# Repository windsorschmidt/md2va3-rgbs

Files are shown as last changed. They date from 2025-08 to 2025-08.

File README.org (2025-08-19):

* About

RGBS video and audio output board for Sega Genesis 2 VA3.

Based on the "Triple Bypass" (3BP for short) circuit originally from
René Richard.  Unlike the TBP which can be configured to work with
several types of Genesis consoles, this board is designed specifically
for the Genesis 2 VA3.

* Features

- Active buffer/amplifiers for audio and video
- Mounts inside console beside main PCB using existing mounting points
- RGBS output on DE-15 (VGA style) connector
- Audio output on 3.5mm phono jack

[[md2va3-rgbs.png?raw=true]]

* Status

Revision 2 PCB tested working.

* References

- https://github.com/db-electronics/triple-bypass-kicad
- https://github.com/tianfeng33/triple-bypass-Version-2

* License

Circuit schematic and PCB layout are licensed under CERN-OHL-S v2.

See [[LICENSE.txt]].

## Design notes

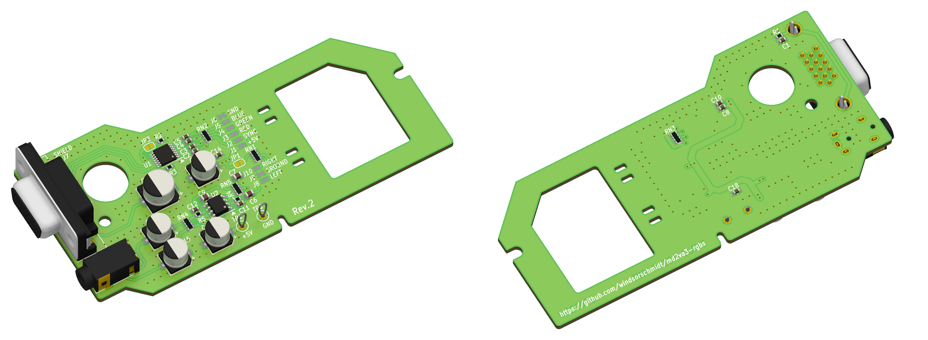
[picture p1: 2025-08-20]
md2va3-rgbs.png

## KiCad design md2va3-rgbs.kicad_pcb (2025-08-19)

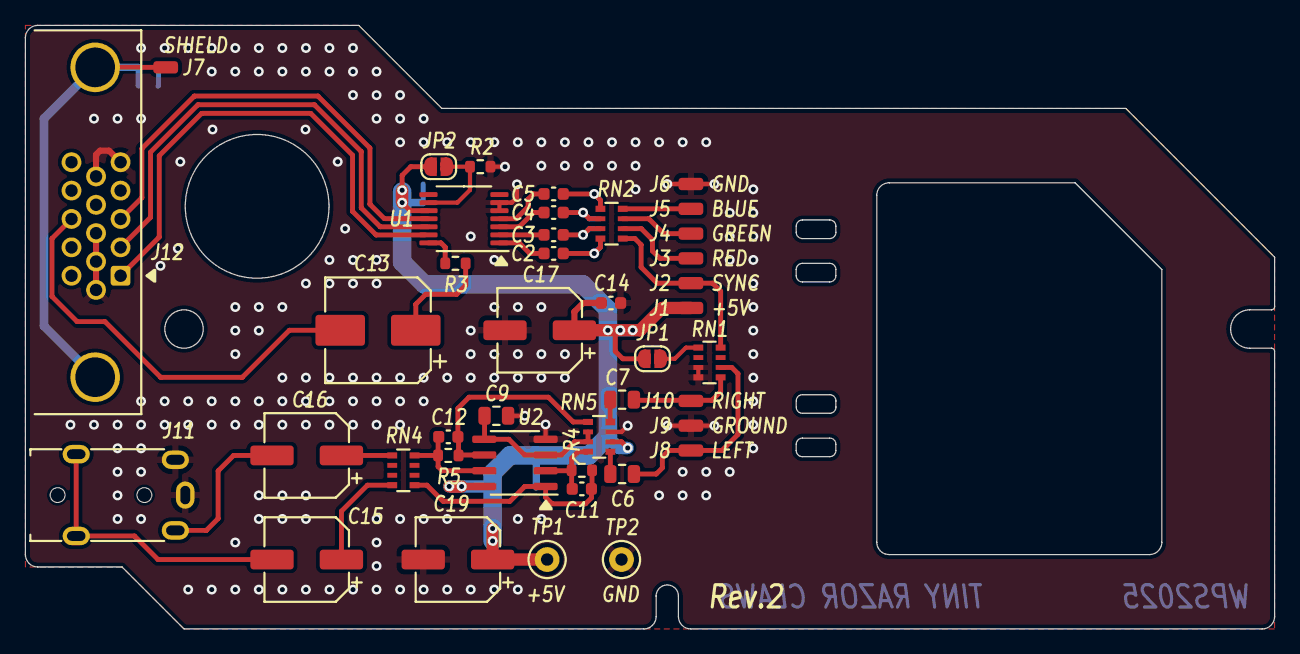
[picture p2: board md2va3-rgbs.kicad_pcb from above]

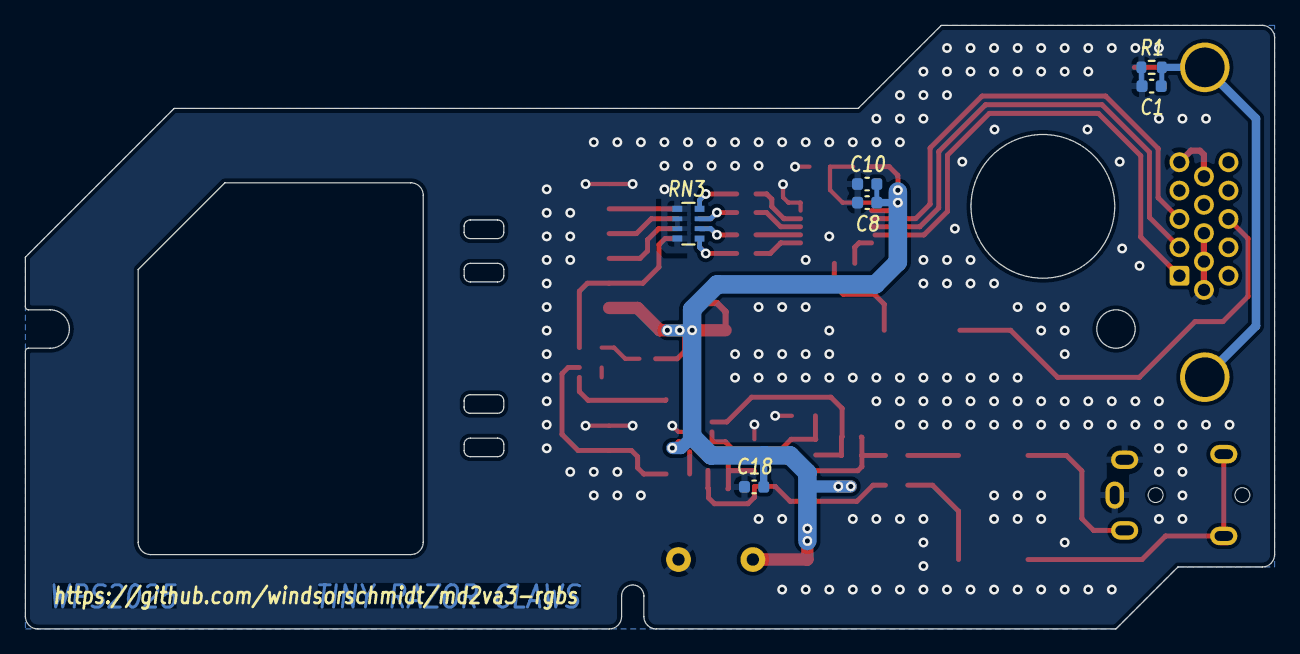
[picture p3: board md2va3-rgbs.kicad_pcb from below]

Board: 2 copper layers, 100.8 x 48.7 mm, 49 parts (6 on the bottom side), 36 nets.

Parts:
C1, C11, C12: 33p; C_0603_1608Metric
C2, C3, C4, C5, C14, C18: 100n; C_0603_1608Metric
C6, C7, C9: 10u; C_0805_2012Metric
C8: 10n; C_0603_1608Metric
C10: 1u; C_0603_1608Metric
C13: 220u; CP_Elec_8x6.2
C15, C16, C17, C19: 47u; CP_Elec_6.3x5.9
J1: +5V; SolderWirePad_1x01_SMD_1x2mm
J2: SYNC_TTL; SolderWirePad_1x01_SMD_1x2mm
J3: R; SolderWirePad_1x01_SMD_1x2mm
J4: G; SolderWirePad_1x01_SMD_1x2mm
J5: B; SolderWirePad_1x01_SMD_1x2mm
J6, J9: GND; SolderWirePad_1x01_SMD_1x2mm
J7: SHIELD; SolderWirePad_1x01_SMD_1x2mm
J8: LEFT; SolderWirePad_1x01_SMD_1x2mm
J10: RIGHT; SolderWirePad_1x01_SMD_1x2mm
J11: 54-00174; Jack_3.5mm_Tensility_54-00174
J12: HD15-SN-25; DSUB-15-HD_Female_Horizontal_P2.29x1.98mm_EdgePinOffset3.03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
JP1: SYNC_PU; SolderJumper-2_P1.3mm_Open_RoundedPad1.0x1.5mm
JP2: LPF; SolderJumper-2_P1.3mm_Open_RoundedPad1.0x1.5mm
MNT1, MNT2: MOUNT_ZIP_TIE; MountingHole_Zip_Tie
R1: 1M; R_0603_1608Metric
R2: 4.7k; R_0603_1608Metric
R3: 75; R_0603_1608Metric
R4, R5: 300k; R_0603_1608Metric
RN1: 2.2k; R_Array_Convex_4x0603
RN2: 5.62k; R_Array_Convex_4x0603
RN3: 1k; R_Array_Convex_4x0603
RN4: 330; R_Array_Convex_4x0603
RN5: 10k; R_Array_Convex_4x0603
TP1: +5V; TestPoint_Loop_D2.50mm_Drill1.0mm
TP2: GND; TestPoint_Loop_D2.50mm_Drill1.0mm
U1: THS7374; TSSOP-14_4.4x5mm_P0.65mm
U2: TLV9162IDR; SOIC-8_3.9x4.9mm_P1.27mm

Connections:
+5V: C8.1, C10.2, C14.1, C17.1, C18.1, C19.1, J1.1, JP1.1 (A), JP2.1 (A), RN5.6 (R3.2), TP1.1, U1.10 (V_{S+}), U2.8 (V+)
/B: J5.1, RN2.4 (R4.1)
/B_IN: C5.1, U1.4 (CH4_IN)
/B_OUT: J12.3, U1.11 (CH4_OUT)
/G: J4.1, RN2.3 (R3.1)
/G_IN: C4.1, U1.3 (CH3_IN)
/G_OUT: J12.2, U1.12 (CH3_OUT)
/LEFT: C6.1, J8.1, RN1.2 (R2.1)
/LEFT_OUT: C15.2, J11.T
/R: J3.1, RN2.2 (R2.1)
/RIGHT: C7.1, J10.1, RN1.1 (R1.1)
/RIGHT_OUT: C16.2, J11.R1
/R_IN: C3.1, U1.2 (CH2_IN)
/R_OUT: J12.1, U1.13 (CH2_OUT)
/SYNC_75: C13.2, J12.13
/SYNC_TTL: J2.1, RN1.4 (R4.1), RN2.1 (R1.1)
/SYNC_TTL_IN: C2.1, U1.1 (CH1_IN)
GND: C1.1, C8.2, C9.2, C10.1, C14.2, C17.2, C18.2, C19.2, J6.1, J9.1, J11.R2, J11.S, J12.5, J12.6, J12.7, J12.8, J12.10, R1.1, R2.1, RN1.7 (R2.2), RN1.8 (R1.2), RN3.5 (R4.2), RN3.6 (R3.2), RN3.7 (R2.2), RN3.8 (R1.2), RN5.7 (R2.2), TP2.1, U1.5 (GND), U1.6 (DISABLE), U2.4 (V-)
GNDPWR: C1.2, J7.1, J12.0, R1.2
unnamed: C13.1, R3.2
unnamed: JP1.2 (B), RN1.5 (R4.2)
unnamed: JP2.2 (B), R2.2, U1.9 (BYPASS)
unnamed: C2.2, RN2.8 (R1.2), RN3.1 (R1.1)
unnamed: C3.2, RN2.7 (R2.2), RN3.2 (R2.1)
unnamed: C4.2, RN2.6 (R3.2), RN3.3 (R3.1)
unnamed: C5.2, RN2.5 (R4.2), RN3.4 (R4.1)
unnamed: C11.2, R4.2, RN4.1 (R1.1), U2.1
unnamed: C15.1, RN4.8 (R1.2)
unnamed: C12.2, R5.2, RN4.4 (R4.1), U2.7
unnamed: C16.1, RN4.5 (R4.2)
unnamed: C12.1, R5.1, RN5.1 (R1.1), U2.6 (-)
unnamed: C7.2, RN5.8 (R1.2)
unnamed: C9.1, RN5.2 (R2.1), RN5.3 (R3.1), U2.3 (+), U2.5 (+)
unnamed: C11.1, R4.1, RN5.4 (R4.1), U2.2 (-)
unnamed: C6.2, RN5.5 (R4.2)
unnamed: R3.1, U1.14 (CH1_OUT)

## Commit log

2025-08-08 better 3D model for d-sub connector
    [md2va3-amp.kicad_pcb]
2025-08-08 update pcb images
2025-08-19 update pcb image
2025-08-19 rename kicad project
    [md2va3-amp.kicad_pcb, md2va3-amp.kicad_sch, sim-audio-amp.kicad_sch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]
2025-08-20 renme files
    [md2va3-rgbs.kicad_pcb, md2va3-rgbs.kicad_sch]

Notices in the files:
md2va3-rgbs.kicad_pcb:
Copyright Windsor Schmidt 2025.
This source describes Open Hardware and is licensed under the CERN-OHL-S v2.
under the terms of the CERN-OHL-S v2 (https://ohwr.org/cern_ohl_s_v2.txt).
